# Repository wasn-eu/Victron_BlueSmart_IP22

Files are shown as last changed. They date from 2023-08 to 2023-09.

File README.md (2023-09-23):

# Victron_BlueSmart_IP22
## Using the BlueSmart IP22 Charger without Bluetooth.
## (c) by [](https://www.wasn.eu)

# all new updates are now under [github://pvtex/Victron_BlueSmart_IP22](https://github.com/pvtex/Victron_BlueSmart_IP22)

- [Connecting to venus](#connecting-to-venus)   
  - [Connect USB to TTL Converter](#connect-usb-to-ttl-converter)    
  - [Connected to venus](#connected-to-venus) 
- [Service Change Charge Current](#service-change-charge-current)
  - [Install](#install)
  - [Config](#config)
  - [Uninstall](#uninstall)
  - [Restart](#restart)
  - [Debugging](#debugging)  
- [Adapter](#adapter)   
  - [Adapter PCB](#adapter-pcb)     

## Connecting to venus
### Connect USB to TTL Converter
     
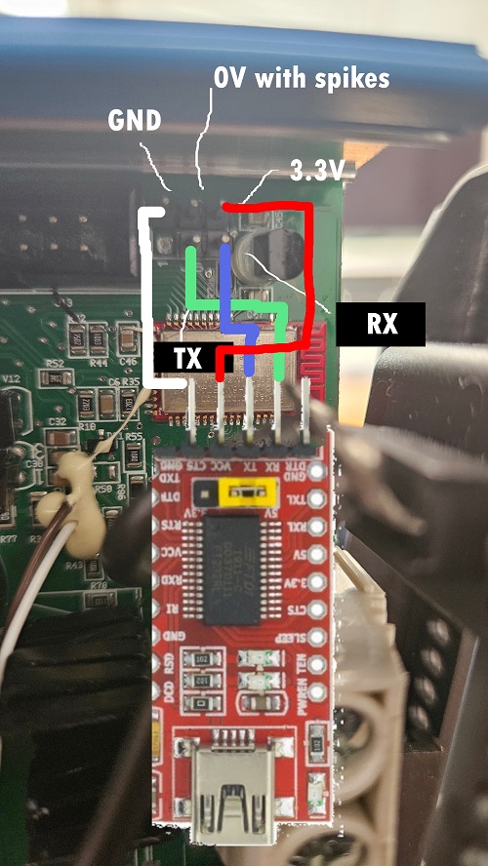
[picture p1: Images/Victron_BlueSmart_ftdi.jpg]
Victron FTDI Schematic

      
On the picture the jumper for the TTL level is wrong. 
IMPORTANT: change the jumper to 3.3V    

You have to use TTL to USB adapter for 3.3V TTL level.   
If you use an isolated adapter you have to connect the 3.3V pin to the adapter, if not dont connect it.   

### Connected to venus

if you connect the ttl to usb cable direct to a venus os device (i have on here running on a raspberry pi 4) 
the charger will show and you can see all information about it:
  
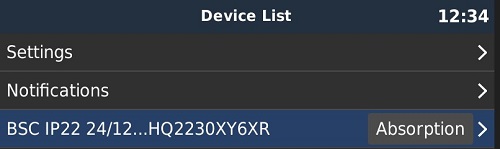
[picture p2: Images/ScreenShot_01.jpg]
      
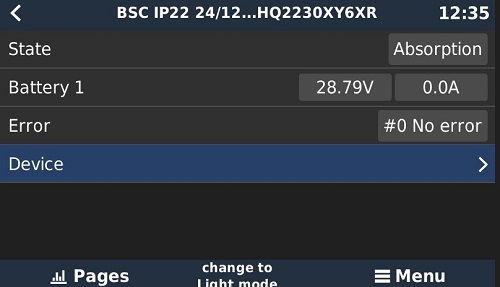
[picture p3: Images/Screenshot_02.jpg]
       
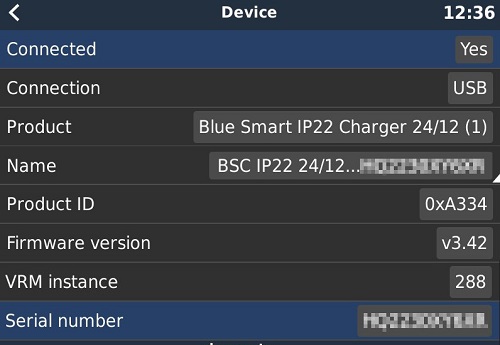
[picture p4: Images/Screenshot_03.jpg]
 

## Service Change Charge Current

In the directory ```bluesmart-charger``` are all files to install this automatic script as a service on venus os.    
First off, a big thanks to [mr-manuel](https://github.com/mr-manuel) that created a bunch of templates that made this possible.   
     
#### Install
Copy the ```bluesmart-charger``` folder to ```/data/etc``` on your Venus OS device
    
Run bash ```/data/etc/bluesmart-charger/install.sh``` as root

The daemon-tools should start this service automatically within seconds.
      
#### Config
Copy or rename the ```config.sample.ini``` to ```config.ini``` in the ```bluesmart-charger``` folder and change it as you need it.    
These values can  be changed in the config file:     

| **KEY** | **DESCRIPTION** | **DEFAULT** |
| :---: | :--- | :---: |
|  **ip** | IP of your venus device | 127.0.0.1 | 
|**phase**| modbus service id for the phase your system is connected to | 820 |
|**interface** | the USB interface of the charger | /dev/ttyUSB1 |
|**intervall** | how often the charging current should be calculated and send to the charger |30 seconds |
|**maxcurrent** | max charging current to limit this value | 12 A |

After changing the config file run the ```restart.sh``` script to activate the new config.     
     
#### Uninstall
Run ```/data/etc/bluesmart-charger/uninstall.sh```
     
#### Restart
Run ```/data/etc/bluesmart-charger/restart.sh```
     
#### Debugging
The logs can be checked with ```tail -n 100 -F /data/log/bluesmart-charger/current | tai64nlocal```

The service status can be checked with svstat: ```svstat /service/bluesmart-charger```

This will output somethink like ```/service/bluesmart-charger: up (pid 5845) 185 seconds```

If the seconds are under 5 then the service crashes and gets restarted all the time. If you do not see anything in the logs you can increase the log level in ```/data/etc/bluesmart-charger/config.ini``` by changing ```logging = WARNING``` to ```logging = INFO``` or ```logging = DEBUG```

## Adapter
### Adapter PCB

I have just created a little adapter pcb with a level shifter and isolation for RX and TX.   
With this you can use a standard ve.direct cable:      
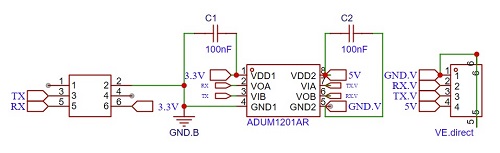
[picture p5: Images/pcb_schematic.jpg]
Adapter Schematic

     
Here is how it looks like:       
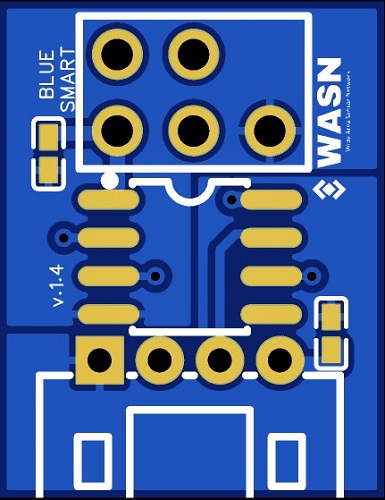
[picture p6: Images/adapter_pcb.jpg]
PCB

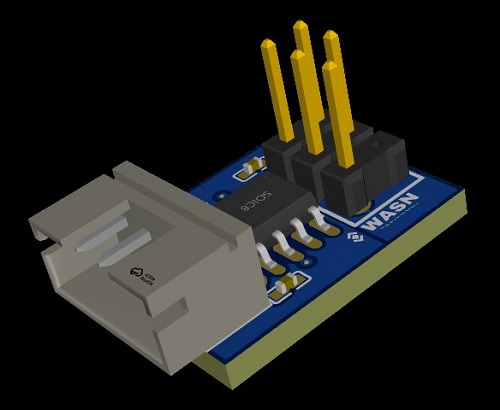
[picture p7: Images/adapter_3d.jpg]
Adapter 3D

      
And there is a little case for it.      
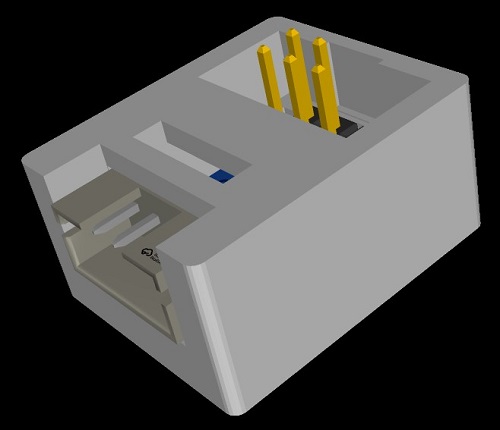
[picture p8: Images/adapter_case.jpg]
Adapter Case


All files needed are in the pcb folder.    

You can use a short (about 10cm) 6pin to 6pin flat ribbon cable with the 6pin sockets to connect the charger to the pcb.   
the cable can be routed outside at the right side of the battery terminals.    

If you need a ready made one just drop me an email.

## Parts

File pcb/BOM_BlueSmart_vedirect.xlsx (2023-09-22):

No. | Quantity | Comment | Designator | Footprint | Value | Manufacturer Part | Manufacturer | Supplier Part | Supplier
1 | 1 | ADUM1201AR | ADUM120 | SOIC-8_L5.0-W4.0-P1.27-LS6.0-BL |  | ADUM1201AR | ADI(亚德诺)/LINEAR | C660256 | LCSC
2 | 1 | A2541WV-2x3P | BLUESMART1 | HDR-TH_6P-P2.54-V-R2-C3-S2.54_A2541WV-2X3P |  | A2541WV-2x3P | CJT(长江连接器) | C225518 | LCSC
3 | 2 | 100nF | C1,C2 | C0402 | 100nF | CT41G-0402-2X1-16V-0.1μF-K(N) | TORCH(火炬) | C141382 | LCSC
4 | 1 | HDGC2001WR-4P | VE.DIRECT1 | CONN-TH_4P-P2.00_HDGC_HDGC2001WR-4P |  | HDGC2001WR-4P | HDGC(华德共创) | C5175241 | LCSC

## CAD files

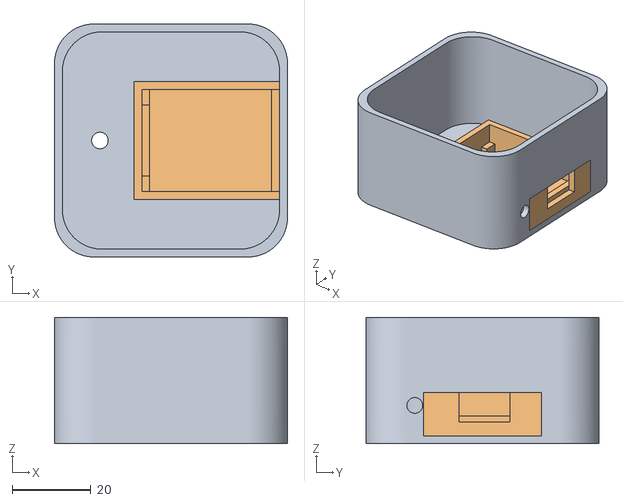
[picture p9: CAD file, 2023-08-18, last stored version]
ESP_BlueSmart_Reader/Wemos_Case_Base1.stl
59.0 x 59.0 x 32.0

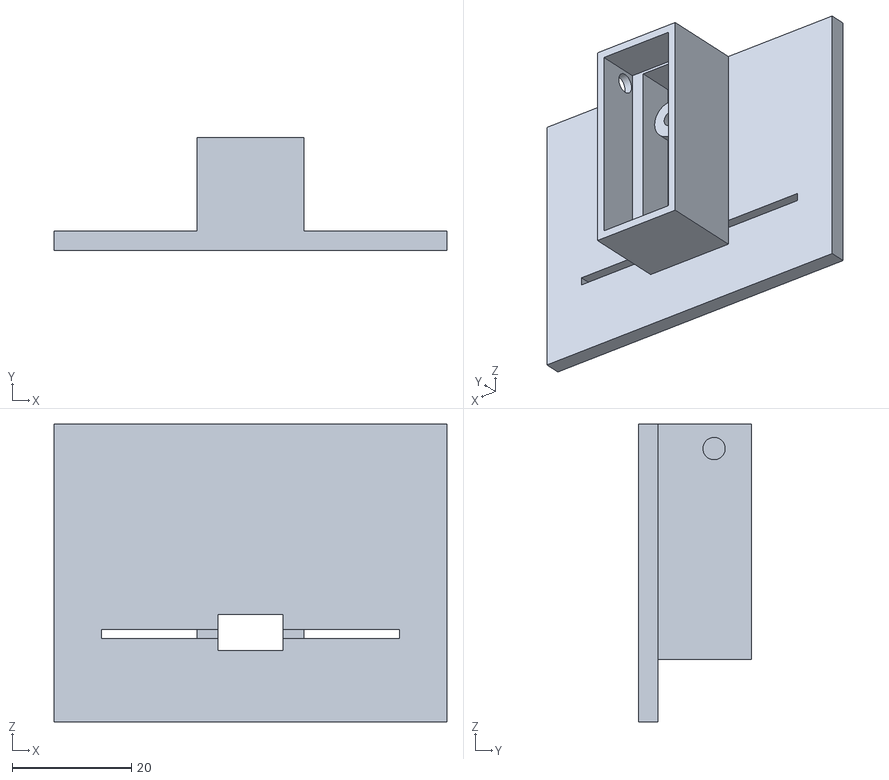
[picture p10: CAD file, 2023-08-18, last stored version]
ESP_BlueSmart_Reader/Stromzähler_v7.stl
66.0 x 19.0 x 50.0

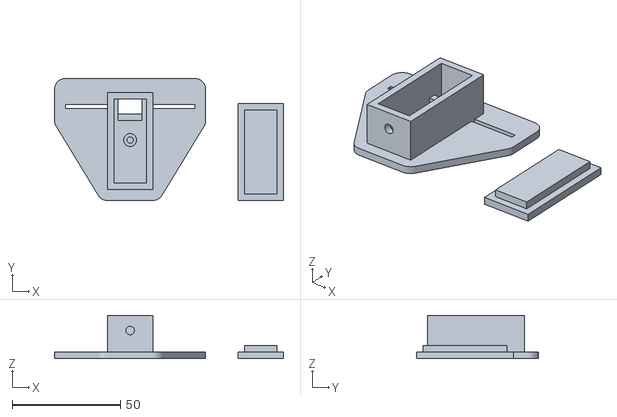
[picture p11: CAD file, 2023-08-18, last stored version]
ESP_BlueSmart_Reader/TCRT5000-module-holder.stl
106.0 x 56.5 x 20.0

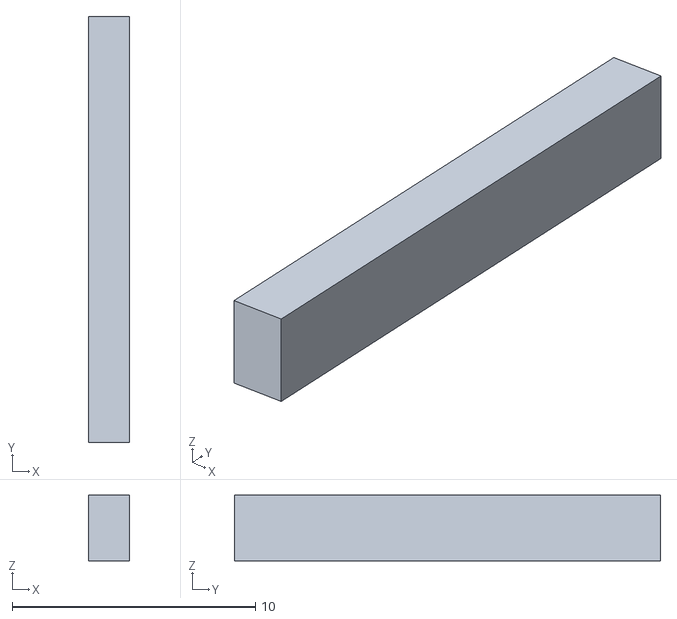
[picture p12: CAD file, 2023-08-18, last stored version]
ESP_BlueSmart_Reader/DIN_Rail_Hook_stopper.stl
1.70 x 17.5 x 2.70

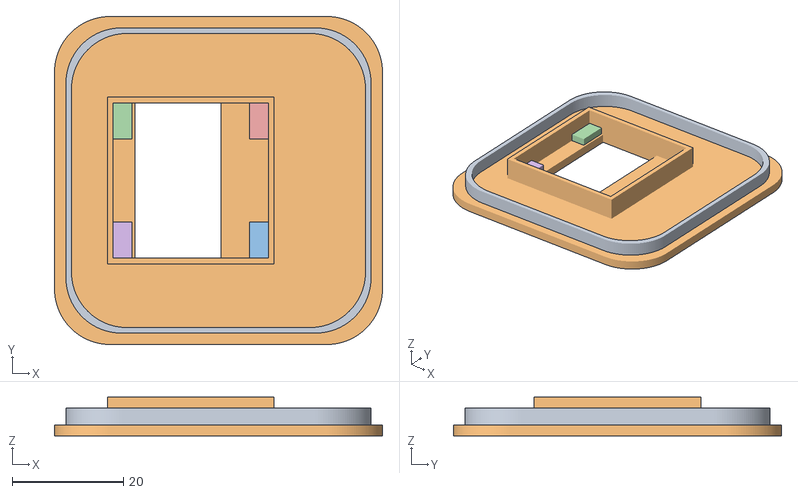
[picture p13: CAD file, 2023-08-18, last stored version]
ESP_BlueSmart_Reader/Wemos_Case_Top_LCD_096.stl
59.0 x 59.0 x 7.00

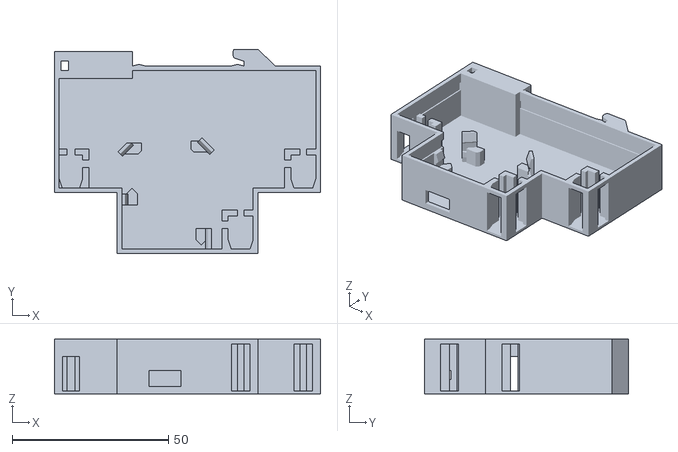
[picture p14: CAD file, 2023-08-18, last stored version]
ESP_BlueSmart_Reader/DIN-Rail_V1_fixed.stl
85.0 x 65.3 x 17.5

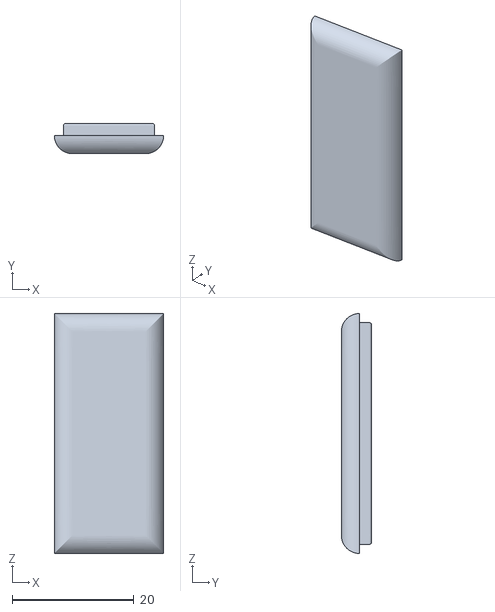
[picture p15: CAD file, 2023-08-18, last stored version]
ESP_BlueSmart_Reader/Deckel.stl
18.0 x 5.00 x 39.5

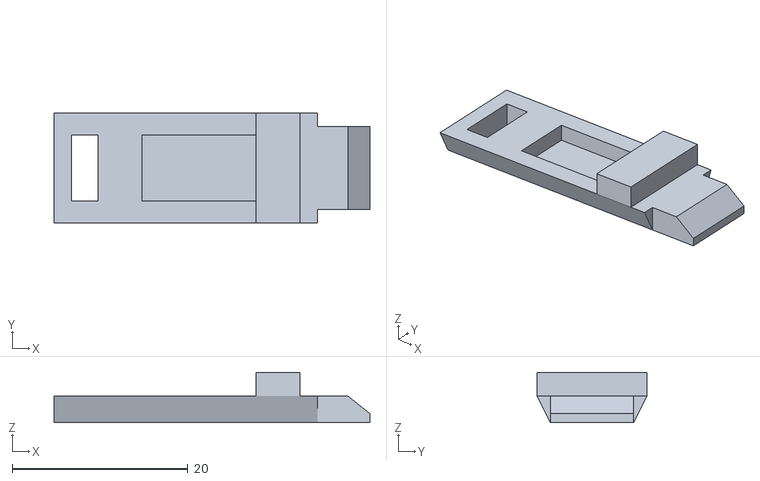
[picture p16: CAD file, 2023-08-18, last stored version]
ESP_BlueSmart_Reader/DIN_Rail_Hook_v1b.stl
36.0 x 12.5 x 5.70

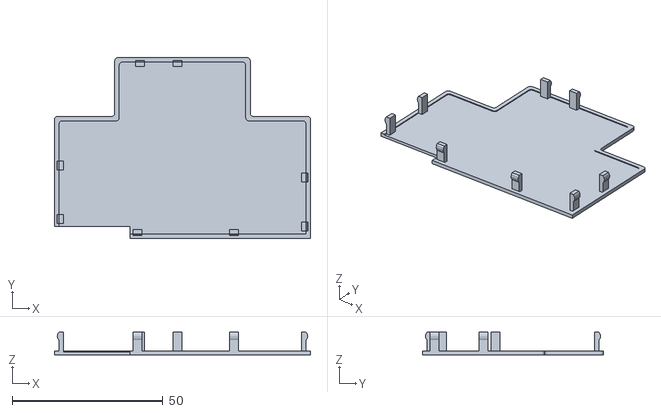
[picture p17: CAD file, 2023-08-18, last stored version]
ESP_BlueSmart_Reader/DIN-Rail_V1_Top_fixed.stl
85.0 x 60.0 x 7.57

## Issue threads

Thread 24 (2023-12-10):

Index out of Range in bluesmart-charger.py

diskmemo, 2023-12-10:
when the current is between 9.5 and 10.5 you get an index out of Range in Line:
msg =  ':8F0ED00' + hexP1[0] + hexP1[1] + '00' + hexP2[0] + hexP2[1] + '\n'

it is because in hexP2 is to short because of a zero value.

to fix it you can add:
       if len(hexP2) < 2:
          hexP2 = "0" + hexP2
after:
 if len(hexP1) < 2:
          hexP1 += "0"

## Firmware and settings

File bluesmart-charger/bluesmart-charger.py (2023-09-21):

#!/usr/bin/env python

from gi.repository import GLib  # pyright: ignore[reportMissingImports]
import platform
import logging
import sys
import os
import time
import json
import configparser  # for config/ini file
import _thread
import serial
from pymodbus.constants import Defaults
from pymodbus.constants import Endian
from pymodbus.client.sync import ModbusTcpClient as ModbusClient
from pymodbus.payload import BinaryPayloadDecoder

# get values from config.ini file
try:
    config_file = (os.path.dirname(os.path.realpath(__file__))) + "/config.ini"
    if os.path.exists(config_file):
        config = configparser.ConfigParser()
        config.read(config_file)
    else:
        print(
            'ERROR:The "'
            + config_file
            + '" is not found. Did you copy or rename the "config.sample.ini" to "config.ini"? The driver restarts in 60 seconds.'
        )
        sleep(60)
        sys.exit()

except Exception:
    exception_type, exception_object, exception_traceback = sys.exc_info()
    file = exception_traceback.tb_frame.f_code.co_filename
    line = exception_traceback.tb_lineno
    print(
        f"Exception occurred: {repr(exception_object)} of type {exception_type} in {file} line #{line}"
    )
    print("ERROR:The driver restarts in 60 seconds.")
    sleep(60)
    sys.exit()

# Get logging level from config.ini
# ERROR = shows errors only
# WARNING = shows ERROR and warnings
# INFO = shows WARNING and running functions
# DEBUG = shows INFO and data/values
if "DEFAULT" in config and "logging" in config["DEFAULT"]:
    if config["DEFAULT"]["logging"] == "DEBUG":
        logging.basicConfig(level=logging.DEBUG)
    elif config["DEFAULT"]["logging"] == "INFO":
        logging.basicConfig(level=logging.INFO)
    elif config["DEFAULT"]["logging"] == "ERROR":
        logging.basicConfig(level=logging.ERROR)
    else:
        logging.basicConfig(level=logging.WARNING)
else:
    logging.basicConfig(level=logging.WARNING)


# get interval
if "DEFAULT" in config and "interval" in config["DEFAULT"]:
    interval = int(config["DEFAULT"]["interval"])
else:
    interval = 30
logging.debug(f"Interval: {interval}") 

# get max charging current
if "DEFAULT" in config and "maxcurrent" in config["DEFAULT"]:
    maxcurrent = int(config["DEFAULT"]["maxcurrent"])
else:
    maxcurrent = 12
logging.debug(f"Max Current: {maxcurrent}") 


# get interface
if "DEFAULT" in config and "interface" in config["DEFAULT"]:
    interface = config["DEFAULT"]["interface"]
else:
    interface = "/dev/ttyUSB1"
logging.debug(f"Interface: {interface}")

# get phase
if "DEFAULT" in config and "phase" in config["DEFAULT"]:
    phase = int(config["DEFAULT"]["phase"])
else:
    phase = 820
logging.debug(f"Phase: {phase}")

# get IP
if "DEFAULT" in config and "ip" in config["DEFAULT"]:
    ip = config["DEFAULT"]["ip"]
else:
    ip = "127.0.0.1"

def main():
  ser = serial.Serial(interface,19200)
  currentold = 0

  while(True):
    current = 0.0 
    chargerstate = 0.0
    Defaults.Timeout = 5
    Defaults.Retries = 5

#    client = ModbusClient(ip, port=502, timeout=3, unit_id=29)
#    result = client.read_input_registers(2318, 1)
#    if not result.isError():
#      decoder = BinaryPayloadDecoder.fromRegisters(result.registers, byteorder=Endian.Big)
#      chargerstate = decoder.decode_16bit_int()
#      logging.info("Charger State:       {0:.0f}".format(chargerstate))      
#    else:
#      logging.error("Error:", result)

    client = ModbusClient(ip, port=502, timeout=3, unit_id=100)
    result = client.read_input_registers(phase, 1)
    if not result.isError():
      decoder = BinaryPayloadDecoder.fromRegisters(result.registers, byteorder=Endian.Big)
      power = decoder.decode_16bit_int()
      if power < currentold:

        current = power / 24 * (-1)
        currentold = current
        current += currentold

        if current > maxcurrent:
          current = maxcurrent
          logging.warning("Charging Current limit!")
        
        logging.info("Grid Power:        {0:.0f}W".format(power))
        logging.info("Grid Current last: {0:.2f}A".format(currentold))
        logging.info("Grid Current:      {0:.2f}A".format(current))
  
        numP1 = (int)(current * 10)
        numP2 = (0x70 - numP1) & 0xFF
        hexP1 = "%X" % (numP1)
        hexP2 = "%X" % (numP2)
        if len(hexP1) < 2:
          hexP1 += "0"
        msg =  ':8F0ED00' + hexP1[0] + hexP1[1] + '00' + hexP2[0] + hexP2[1] + '\n'
        logging.debug("VE.direct out: " + msg)
        ser.write(msg.encode())
      else:
        logging.info("Grid Power:    {0:.0f}W".format(power))
        logging.info("Charging off")
    else:
      logging.error("Error:", result)
  
    time.sleep(interval) 

if __name__ == "__main__":
    main() 

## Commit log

2023-08-18 ESP8266 firmware for reading voltage and current
    [DIN-Rail_V1_Top_fixed.stl, DIN-Rail_V1_fixed.stl, DIN_Rail_Hook_stopper.stl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]
2023-08-18 deleted unneeded files
    [DIN-Rail_V1_Top_fixed.stl, DIN-Rail_V1_fixed.stl, DIN_Rail_Hook_stopper.stl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]
2023-08-21 adapter pcb
2023-08-21 PCB Files uploaded
    [BOM_PCB_BlueSmart_vedirect_2_2023-08-22.csv, PickAndPlace_PCB_BlueSmart_vedirect_2_2023-08-22.csv]
2023-09-10 new PCB
    [BOM_PCB_BlueSmart_vedirect_2_2023-08-22.csv, PickAndPlace_PCB_BlueSmart_vedirect_2_2023-08-22.csv]
2023-09-10 added new PCB files
    [BOM_BlueSmart_vedirect_BlueSmart_vedirect.xlsx, PickAndPlace_PCB_BlueSmart_vedirect.xlsx]
2023-09-10 added Modbus Register sheet
    [CCGX-Modbus-TCP-register-list-3.00.xlsx]
2023-09-11 new PCB Files
    [BOM_BlueSmart_vedirect_BlueSmart_vedirect.xlsx, PickAndPlace_PCB_BlueSmart_vedirect.xlsx]
2023-09-14 added schematic for adapter
2023-09-15 Updated schematic
    [BOM_BlueSmart_vedirect_PCB_BlueSmart_vedirect.xlsx, PickAndPlace_PCB_BlueSmart.xlsx]
2023-09-16 Updated PCN
    [BOM_BlueSmart_vedirect_PCB_BlueSmart_vedirect.xlsx, PickAndPlace_PCB_BlueSmart.xlsx]
2023-09-21 added setting for max charging current to service
2023-09-21 updated usb adapter schematic
2023-09-22 changed adapter PCB to cheaper made with partial through hole design
    [BOM_BlueSmart_vedirect_PCB_BlueSmart_vedirect.xlsx]
2023-09-22 changed pcb image resolution
2023-09-22 new adpater case
2023-09-22 updated PCB images
2023-09-22 updated gerber file
